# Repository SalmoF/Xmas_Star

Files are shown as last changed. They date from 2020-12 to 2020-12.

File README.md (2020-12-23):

# Xmas_Star
A star shaped PCB with an integrated ATMEGA32U4, an high precision temperature sensor, ToF sensor and LEDs.
Realized for the Christmas PCB challenge by JLCPCB (https://jlcpcb.com)
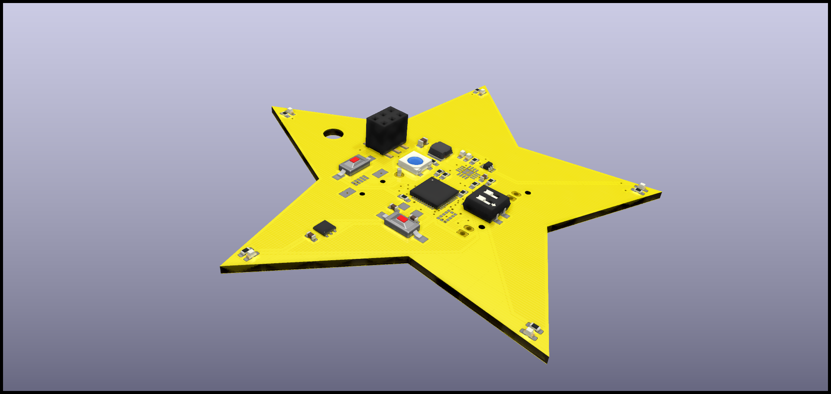
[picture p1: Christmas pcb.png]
plot


The device has two operation modes selectable by the on board DIP switch, the default mode the PCB act as a normal
Christmas ornament with its 5 yellow LEDs and an RGB making various light effects (user button used to switch effects manually).
With the second operation mode the device work as a smart device for keeping the distance of a meter and an half 
using a ToF sensor (VL53L1) for every distance above 2 meters the RGB blinks green every 20sec, above 1.5meter green
and yellow toggle each 15 sec, above 1 meter yellow every 10sec and below a meter red blinking every second.
Then if you press the user button the device will start reading the temperature.

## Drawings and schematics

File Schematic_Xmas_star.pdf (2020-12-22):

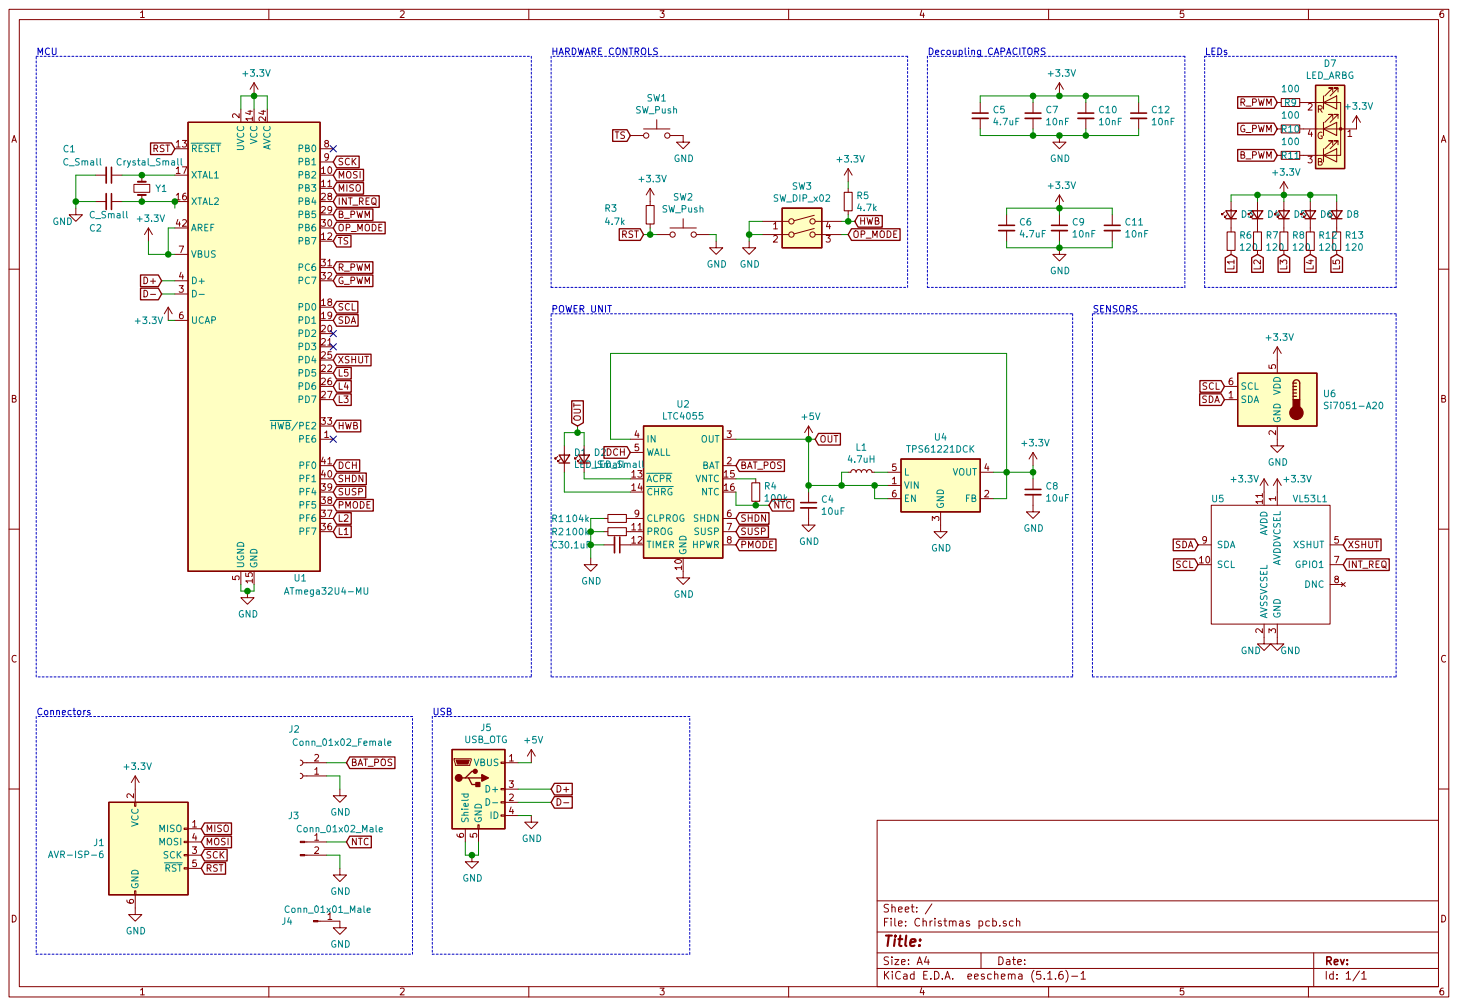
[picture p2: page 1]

2 PD2 20 PD3 21 PD5 22 AVCC 24 PD4 25 PD6 26 PD7 27 PB4 28 PB5 29 D- 3 PB6 30 PC6 31 PC7 32 HWB/PE2 33 PF7 36 PF6 37 PF5 38 PF4 39 D+ 4 PF1 40 PF0 41 AREF 42 UGND

3 XSHUT 5 GPIO1 7 DNC 8 SDA 9 U5 VL53L1 GND GND

2 SCK 3 MOSI 4 RST 5 GND

File: Christmas pcb.sch Sheet: /
Id: 1/1 Title:

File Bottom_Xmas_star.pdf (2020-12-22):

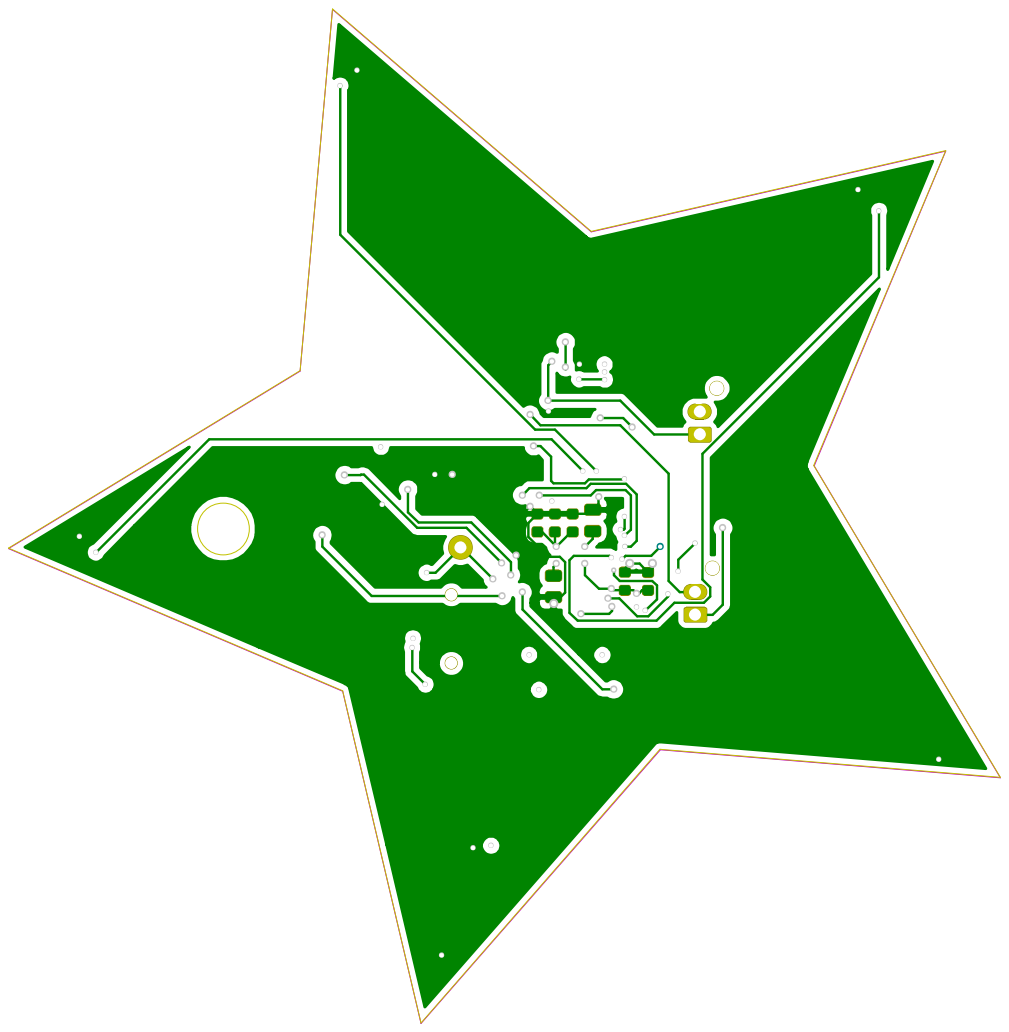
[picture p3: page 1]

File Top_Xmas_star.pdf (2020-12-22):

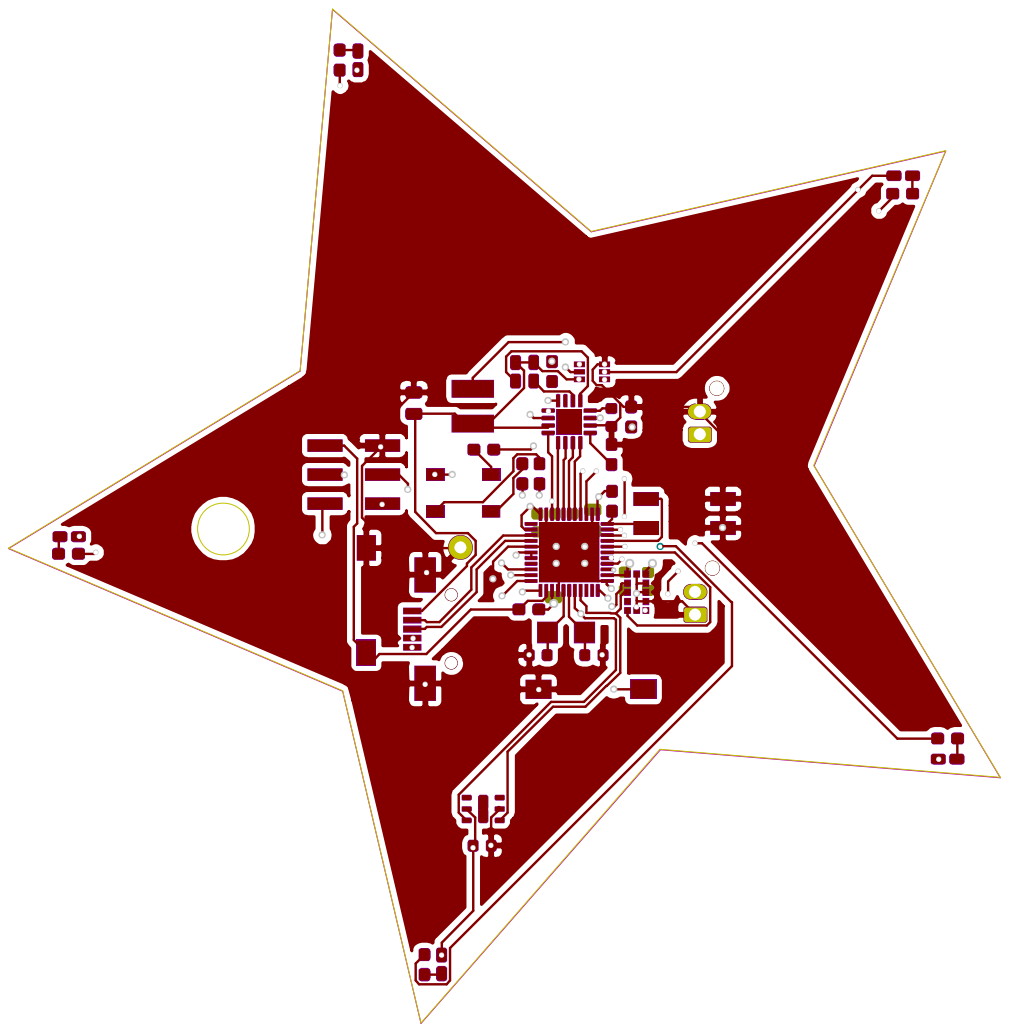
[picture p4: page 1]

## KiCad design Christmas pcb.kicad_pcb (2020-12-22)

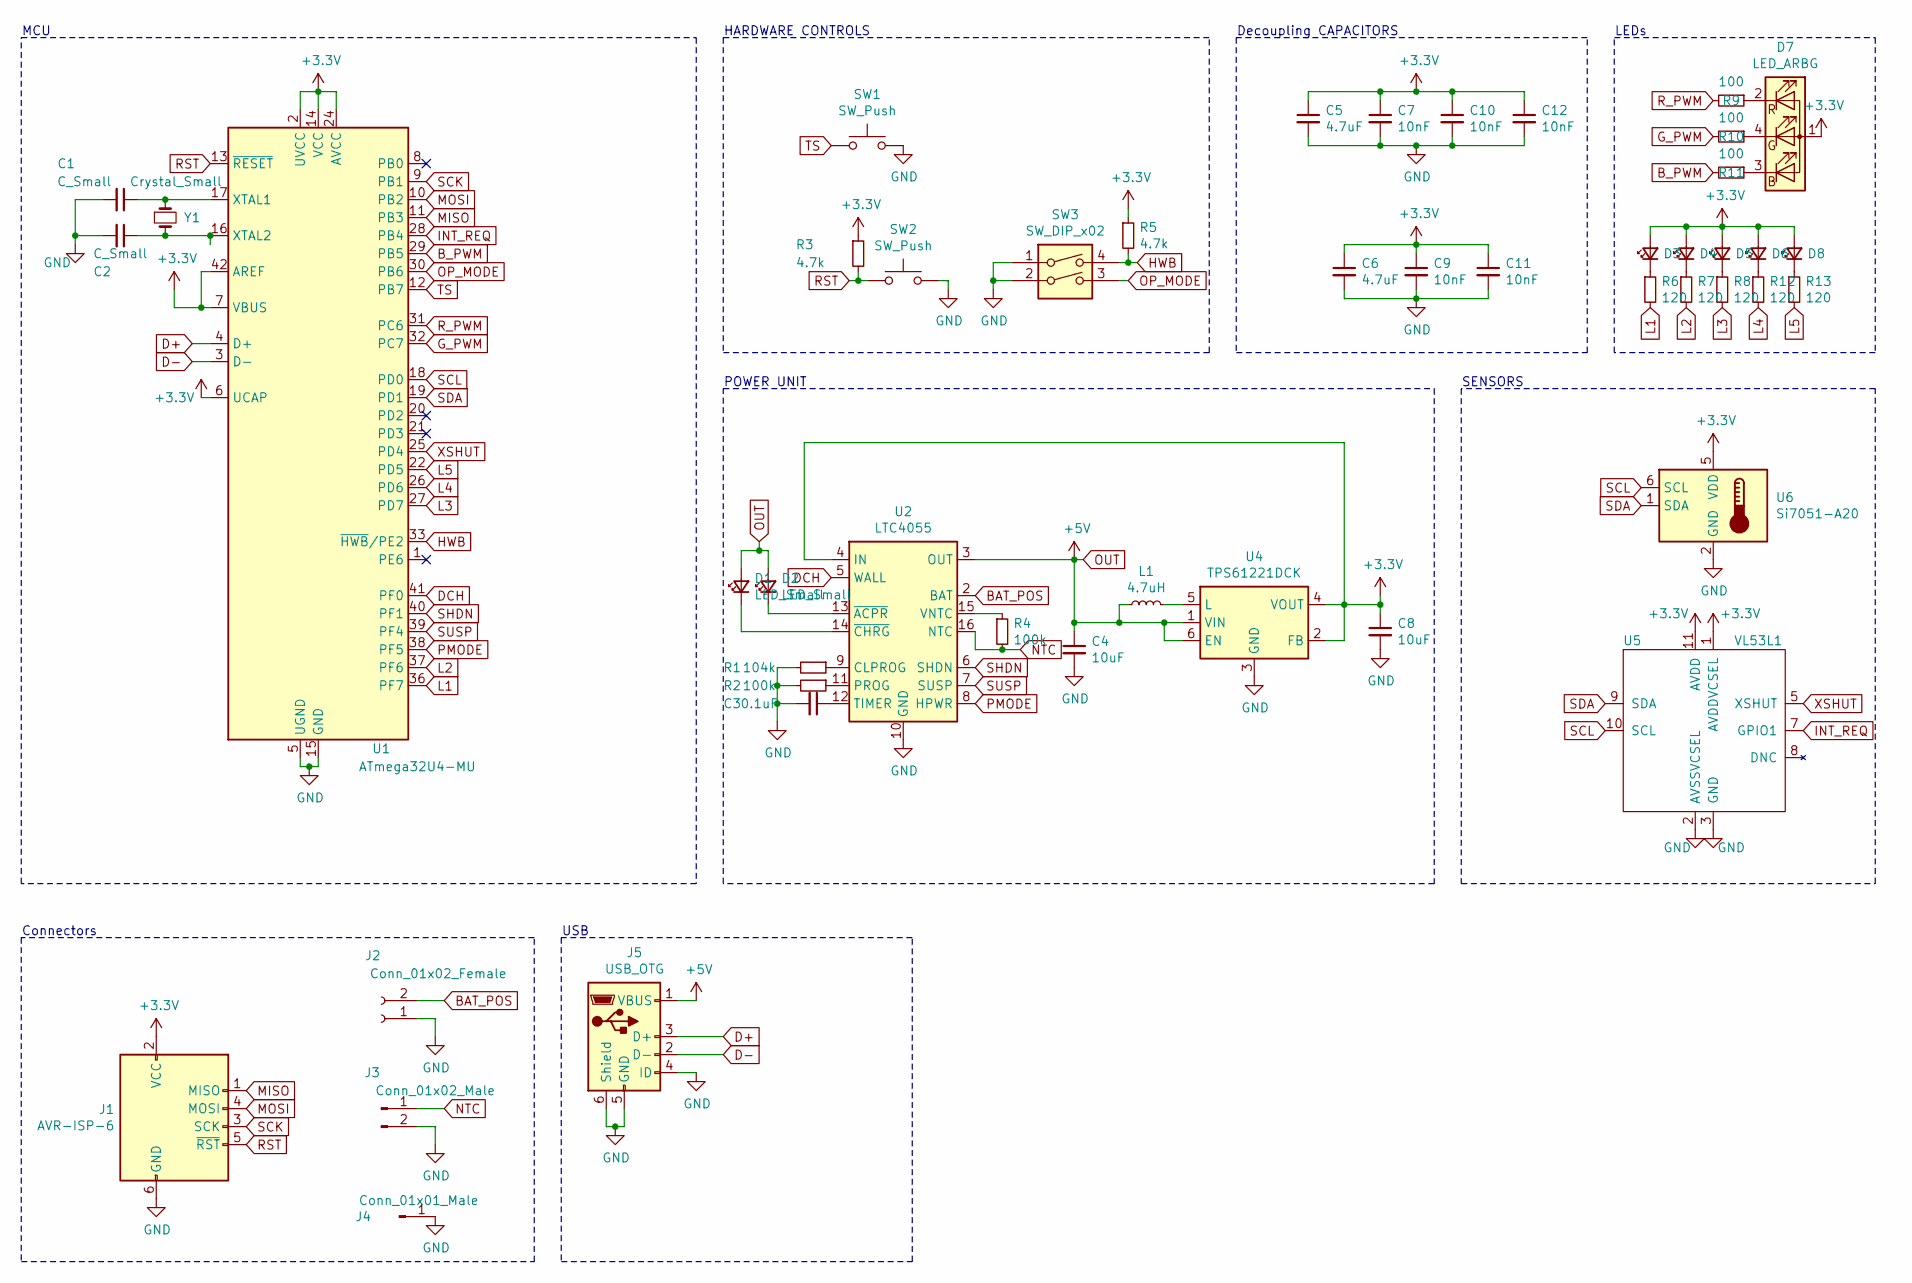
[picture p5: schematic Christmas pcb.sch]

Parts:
C1, C2: C_Small; C_0603_1608Metric
C3: 0.1uF; C_0603_1608Metric
C4: 10uF; C_0805_2012Metric
C5, C6: 4.7uF; C_0805_2012Metric
C7, C9, C10, C11, C12: 10nF; C_0603_1608Metric
C8: 10uF; C_0603_1608Metric
D1, D2, D3, D4, D5, D6, D8: LED_Small; LED_0603_1608Metric_Castellated
D7: LED_ARBG; LED_WS2812B_PLCC4_5.0x5.0mm_P3.2mm
J1: AVR-ISP-6; PinSocket_2x03_P2.54mm_Vertical_SMD
J2: Conn_01x02_Female; JST_JWPF_B02B-JWPF-SK-R_1x02_P2.00mm_Vertical
J3: Conn_01x02_Male; JST_JWPF_B02B-JWPF-SK-R_1x02_P2.00mm_Vertical
J4: Conn_01x01_Male; Pin_D1.0mm_L10.0mm
J5: USB_OTG; USB_Micro-AB_Molex_47590-0001
L1: 4.7uH; L_Bourns-SRN4018
R1: 104k; R_0603_1608Metric_Pad1.05x0.95mm_HandSolder
R2, R4: 100k; R_0603_1608Metric_Pad1.05x0.95mm_HandSolder
R3, R5: 4.7k; R_0603_1608Metric_Pad1.05x0.95mm_HandSolder
R6, R7, R8, R12, R13: 120; R_0603_1608Metric_Pad1.05x0.95mm_HandSolder
R9, R10, R11: 100; R_0603_1608Metric_Pad1.05x0.95mm_HandSolder
SW1, SW2: SW_Push; SW_SPST_FSMSM
SW3: SW_DIP_x02; SW_DIP_SPSTx02_Slide_6.7x6.64mm_W6.73mm_P2.54mm_LowProfile_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
U1: ATmega32U4-MU; QFN-44-1EP_7x7mm_P0.5mm_EP5.2x5.2mm
U2: LTC4055; QFN-16-1EP_4x4mm_P0.65mm_EP2.15x2.15mm
U4: TPS61221DCK; Texas_R-PDSO-G6
U5: VL53L1; VL53L1CBV0FY&slash_1
U6: Si7051-A20; DFN-6-1EP_3x3mm_P1mm_EP1.5x2.4mm
Y1: Crystal_Small; Crystal_SMD_MicroCrystal_CC7V-T1A-2Pin_3.2x1.5mm_HandSolder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

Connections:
+3V3: C5.1, C6.1, C7.1, C8.1, C9.1, C10.1, C11.1, C12.1, D3.2 (A), D4.2 (A), D5.2 (A), D6.2 (A), D7.1 (A), D8.2 (A), J1.2 (VCC), R3.1, R5.1, U1.2 (UVCC), U1.6 (UCAP), U1.7 (VBUS), U1.14 (VCC), U1.24 (AVCC), U1.34 (VCC), U1.42 (AREF), U1.44 (AVCC), U2.1 (IN), U2.4 (IN), U4.2 (FB), U4.4 (VOUT), U5.1 (AVDDVCSEL), U5.11 (AVDD), U6.5 (VDD)
BAT_POS: J2.2, U2.2 (BAT)
B_PWM: R11.2, U1.29 (PB5)
D+: J5.3 (D+), U1.4 (D+)
D-: J5.2 (D-), U1.3 (D-)
DCH: U1.41 (PF0), U2.5 (WALL)
GND: C1.2, C2.2, C3.2, C4.2, C5.2, C6.2, C7.2, C8.2, C9.2, C10.2, C11.2, C12.2, J1.6 (GND), J2.1, J3.2, J4.1, J5.4 (ID), J5.5 (GND), J5.6 (Shield), R1.2, R2.2, SW1.2, SW2.2, SW3.1, SW3.2, U1.5 (UGND), U1.15 (GND), U1.23 (GND), U1.35 (GND), U1.43 (GND), U1.45 (GND), U2.10 (GND), U2.17 (GND), U4.3 (GND), U5.2 (AVSSVCSEL), U5.3 (GND), U5.4 (GND2), U5.6 (GND3), U5.12 (GND4), U6.2 (GND)
G_PWM: R10.2, U1.32 (PC7)
HWB: R5.2, SW3.4, U1.33 (~HWB~/PE2)
INT_REQ: U1.28 (PB4), U5.7 (GPIO1)
L1: R6.2, U1.36 (PF7)
L2: R7.2, U1.37 (PF6)
L3: R8.2, U1.27 (PD7)
L4: R12.2, U1.26 (PD6)
L5: R13.2, U1.22 (PD5)
MISO: J1.1 (MISO), U1.11 (PB3)
MOSI: J1.4 (MOSI), U1.10 (PB2)
NTC: J3.1, R4.2, U2.16 (NTC)
unnamed: C1.1, U1.17 (XTAL1), Y1.1
unnamed: C2.1, U1.16 (XTAL2), Y1.2
unnamed: C3.1, U2.12 (TIMER)
unnamed: D1.1 (K), U2.14 (~CHRG)
unnamed: D2.1 (K), U2.13 (~ACPR)
unnamed: D3.1 (K), R6.1
unnamed: D4.1 (K), R7.1
unnamed: D5.1 (K), R8.1
unnamed: D6.1 (K), R12.1
unnamed: D7.2 (RK), R9.1
unnamed: D7.3 (BK), R11.1
unnamed: D7.4 (GK), R10.1
unnamed: D8.1 (K), R13.1
unnamed: L1.2, U4.5 (L)
unnamed: R1.1, U2.9 (CLPROG)
unnamed: R2.1, U2.11 (PROG)
unnamed: R4.1, U2.15 (VNTC)
OP_MODE: SW3.3, U1.30 (PB6)
OUT: C4.1, D1.2 (A), D2.2 (A), J5.1 (VBUS), L1.1, U2.3 (OUT), U4.1 (VIN), U4.6 (EN)
PMODE: U1.38 (PF5), U2.8 (HPWR)
RST: J1.5 (~RST), R3.2, SW2.1, U1.13 (~RESET)
R_PWM: R9.2, U1.31 (PC6)
SCK: J1.3 (SCK), U1.9 (PB1)
SCL: U1.18 (PD0), U5.10 (SCL), U6.6 (SCL)
SDA: U1.19 (PD1), U5.9 (SDA), U6.1 (SDA)
SHDN: U1.40 (PF1), U2.6 (SHDN)
SUSP: U1.39 (PF4), U2.7 (SUSP)
TS: SW1.1, U1.12 (PB7)
XSHUT: U1.25 (PD4), U5.5 (XSHUT)

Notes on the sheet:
USB
POWER UNIT
Connectors
MCU
HARDWARE CONTROLS
SENSORS
LEDs
Decoupling CAPACITORS

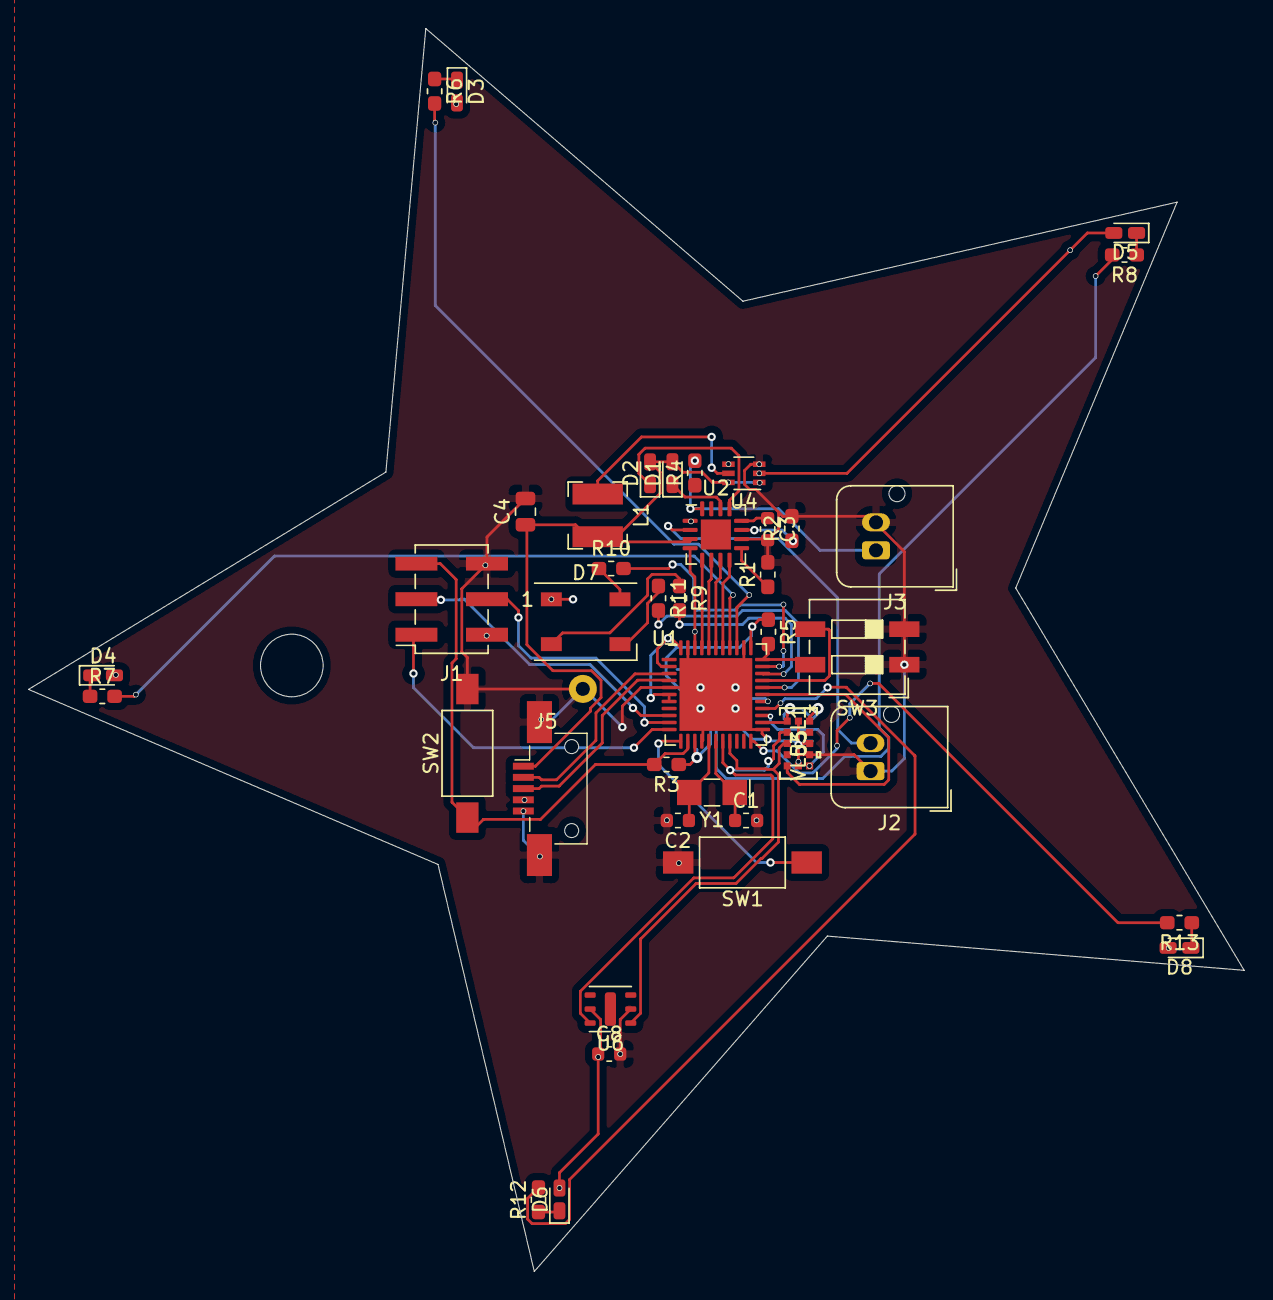
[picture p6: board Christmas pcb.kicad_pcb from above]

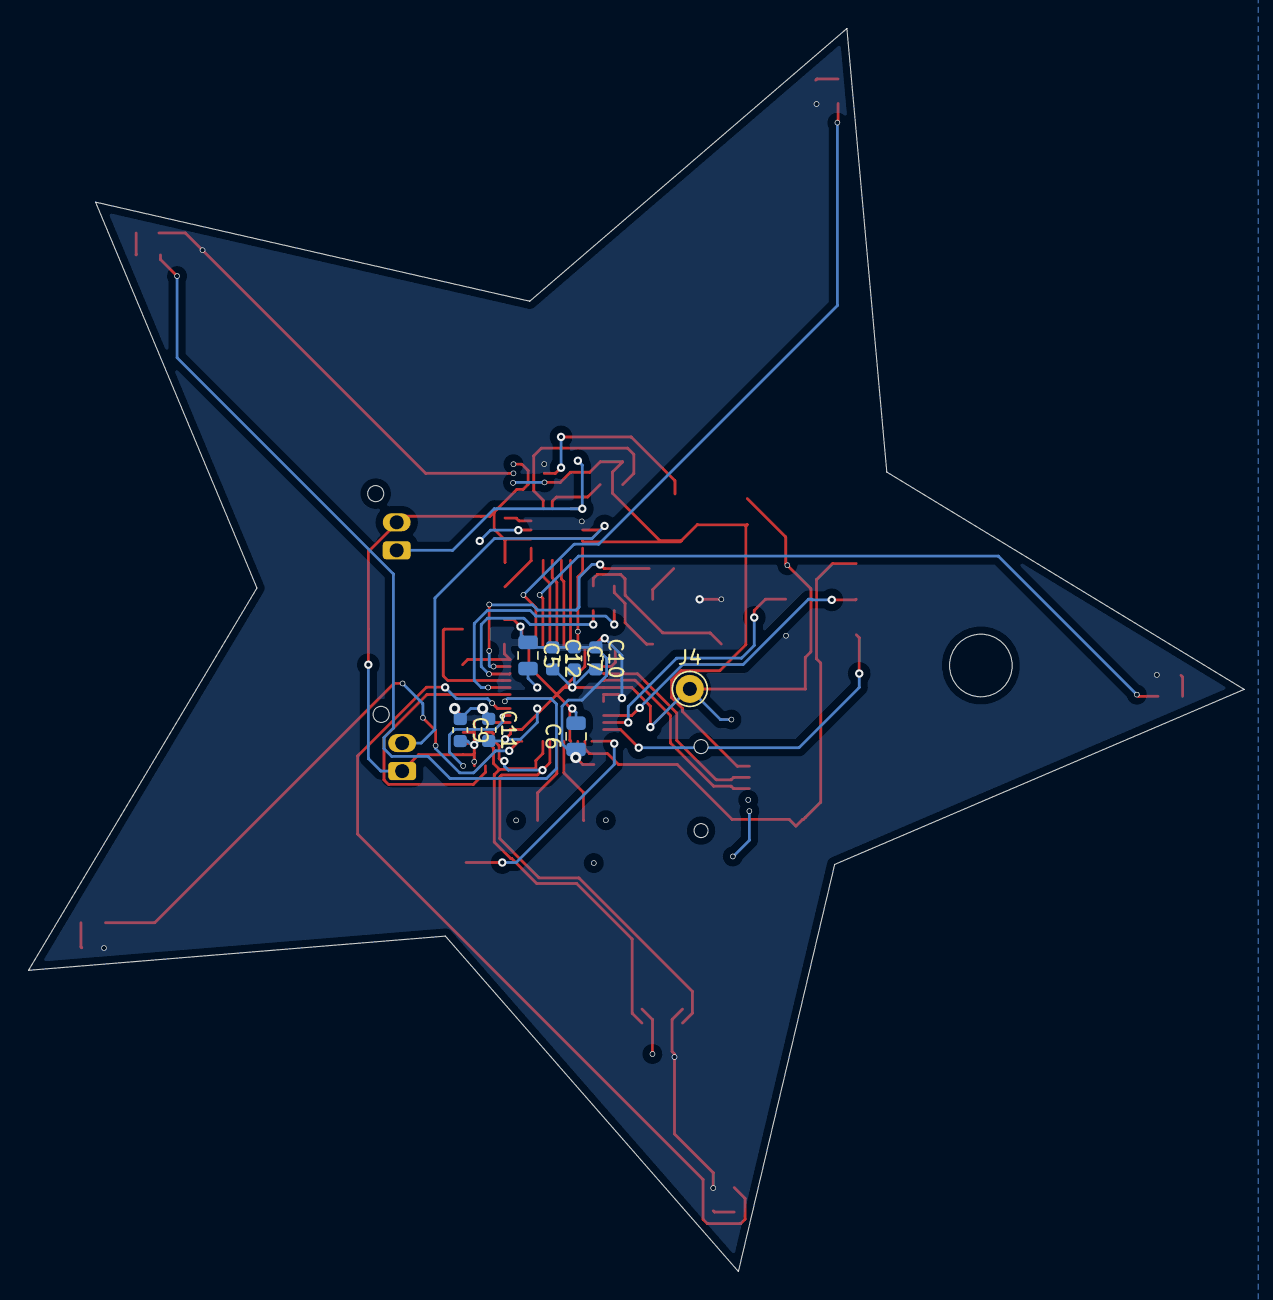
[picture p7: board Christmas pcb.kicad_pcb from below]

Board: 2 copper layers, 86.8 x 88.8 mm, 48 parts (8 on the bottom side), 47 nets.

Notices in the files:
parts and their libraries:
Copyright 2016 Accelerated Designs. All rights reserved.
